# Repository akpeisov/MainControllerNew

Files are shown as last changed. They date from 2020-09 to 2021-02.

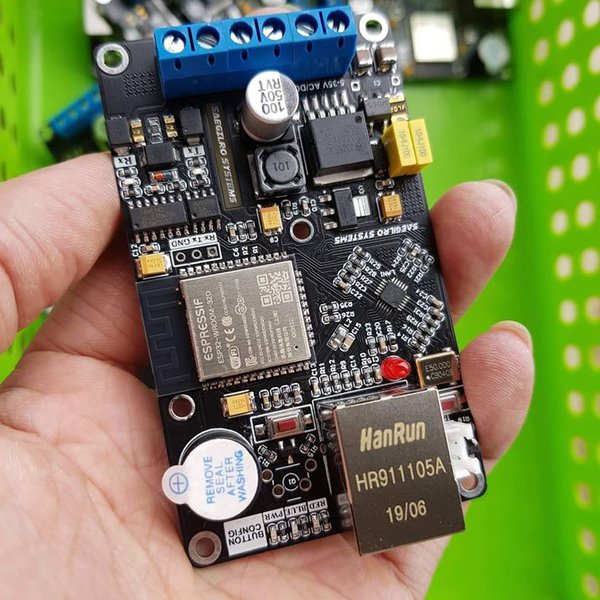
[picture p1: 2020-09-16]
esp32_example.jpg

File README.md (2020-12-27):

# MainControllerNew
Main controller on ESP32 (new version)

Переключение между кварцем и есп
(Top) - Component config - Ethernet - Support ESP32 internal EMAC controller - RMII clock mode

Flash

FT232	ESP32
TX	RX
RX	TX
DTR	GPIO0
RTS	EN

MQTT
Основное устройство (задается в параметрах)/slaveid/outputid

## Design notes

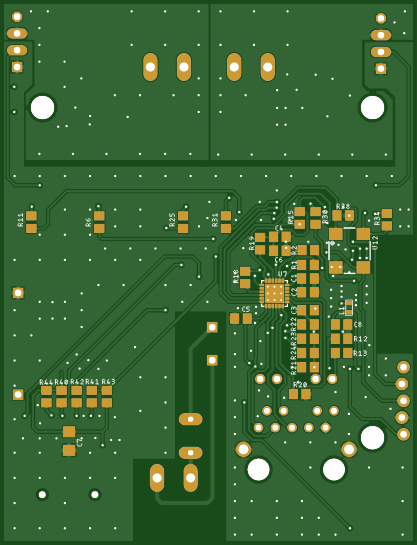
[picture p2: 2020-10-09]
board/back.png

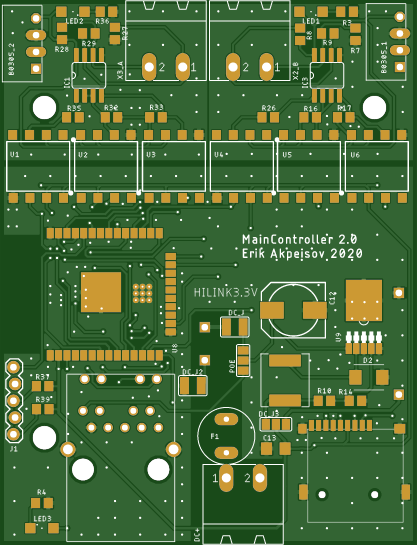
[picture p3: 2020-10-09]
board/face.png

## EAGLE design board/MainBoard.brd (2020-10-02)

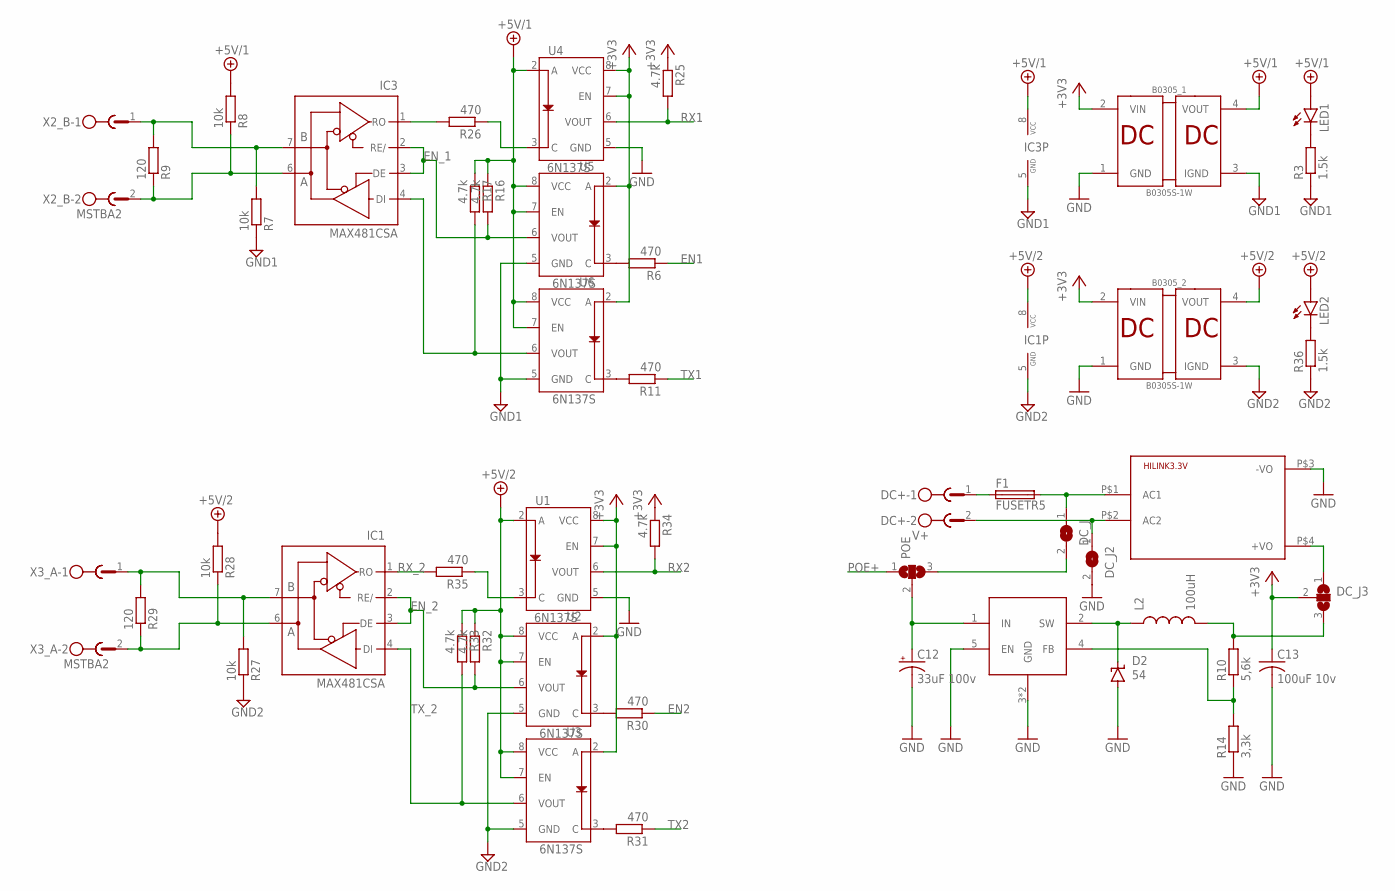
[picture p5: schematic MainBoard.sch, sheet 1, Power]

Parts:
B0305_1, B0305_2: B0305S-1W; B_S-1W
C12: 33uF 100v; 150CLZ-0810
C13: 100uF 10v; C1206
D2: 54; SMBJ
DC+: V+; MSTBA2
DC_J, DC_J2: SJW
DC_J3: SJ2W; SJ_2
F1: FUSETR5; TR5
HILINK3.3V: HLK-PM013W; HLK-PM01
IC1, IC3: MAX481CSA; SO08
L2: 100uH; CR75
LED1, LED2: LEDSML1206; SML1206
POE: SJ2W; SJ_2
R3, R36: 1.5k; R0805
R6, R11, R26, R30, R31, R35: 470; R0805
R7, R8, R27, R28: 10k; R0805
R9, R29: 120; R0805
R10: 5,6k; R0805
R14: 3,3k; R0805
R16, R17, R25, R32, R33, R34: 4.7k; R0805
U1, U2, U3, U4, U5, U6: 6N137S; 8-SMD
U9: XL7015; TO252-51
X2_B, X3_A: MSTBA2

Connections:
+3V3: B0305_1.2 (VIN), B0305_2.2 (VIN), C13.1, DC_J3.2, R25.1, R34.1, U1.7 (EN), U1.8 (VCC), U2.2 (A), U3.2 (A), U4.7 (EN), U4.8 (VCC), U5.2 (A), U6.2 (A); also elsewhere on the board
+5V/1: B0305_1.4 (VOUT), IC3.8 (VCC), LED1.A, R8.2, R16.1, R17.1, U4.2 (A), U5.7 (EN), U5.8 (VCC), U6.7 (EN), U6.8 (VCC)
+5V/2: B0305_2.4 (VOUT), IC1.8 (VCC), LED2.A, R28.2, R32.1, R33.1, U1.2 (A), U2.7 (EN), U2.8 (VCC), U3.7 (EN), U3.8 (VCC)
EN1: R6.1; also elsewhere on the board
EN2: R30.1; also elsewhere on the board
EN_1: IC3.2 (RE/), IC3.3 (DE), R16.2, U5.6 (VOUT)
EN_2: IC1.2 (RE/), IC1.3 (DE), R32.2, U2.6 (VOUT)
GND: B0305_1.1 (GND), B0305_2.1 (GND), C12.-, C13.2, D2.A, DC_J2.2, HILINK3.3V.P$3 (-VO), R14.1, U1.5 (GND), U4.5 (GND), U9.3 (GND), U9.5 (EN), U9.GND; also elsewhere on the board
GND1: B0305_1.3 (IGND), IC3.5 (GND), R3.1, R7.1, U5.5 (GND), U6.5 (GND)
GND2: B0305_2.3 (IGND), IC1.5 (GND), R27.1, R36.1, U2.5 (GND), U3.5 (GND)
unnamed: LED1.C, R3.2
unnamed: IC3.7 (B), R7.2, R9.2, X2_B.1
unnamed: IC3.6 (A), R8.1, R9.1, X2_B.2
unnamed: R10.1, R14.2, U9.4 (FB)
unnamed: DC_J.2, POE.3
unnamed: D2.C, L2.P$1 (1), U9.2 (SW)
unnamed: DC+.2, DC_J2.1, HILINK3.3V.P$2 (AC2)
unnamed: DC+.1, F1.1
unnamed: DC_J3.3, L2.P$2 (2), R10.2
unnamed: R6.2, U5.3 (C)
unnamed: R11.2, U6.3 (C)
unnamed: IC1.7 (B), R27.2, R29.2, X3_A.1
unnamed: R26.1, U4.3 (C)
unnamed: IC1.6 (A), R28.1, R29.1, X3_A.2
unnamed: R30.2, U2.3 (C)
unnamed: R31.2, U3.3 (C)
unnamed: R35.1, U1.3 (C)
unnamed: LED2.C, R36.2
unnamed: DC_J3.1, HILINK3.3V.P$4 (+VO)
unnamed: C12.+, POE.2, U9.1 (IN)
unnamed: DC_J.1, F1.2, HILINK3.3V.P$1 (AC1)
POE+: POE.1; also elsewhere on the board
RX1: R25.2, U4.6 (VOUT); also elsewhere on the board
RX2: R34.2, U1.6 (VOUT); also elsewhere on the board
RX485: IC3.1 (RO), R26.2
RX_2: IC1.1 (RO), R35.2
TX1: R11.1; also elsewhere on the board
TX2: R31.1; also elsewhere on the board
TX485: IC3.4 (DI), R17.2, U6.6 (VOUT)
TX_2: IC1.4 (DI), R33.2, U3.6 (VOUT)

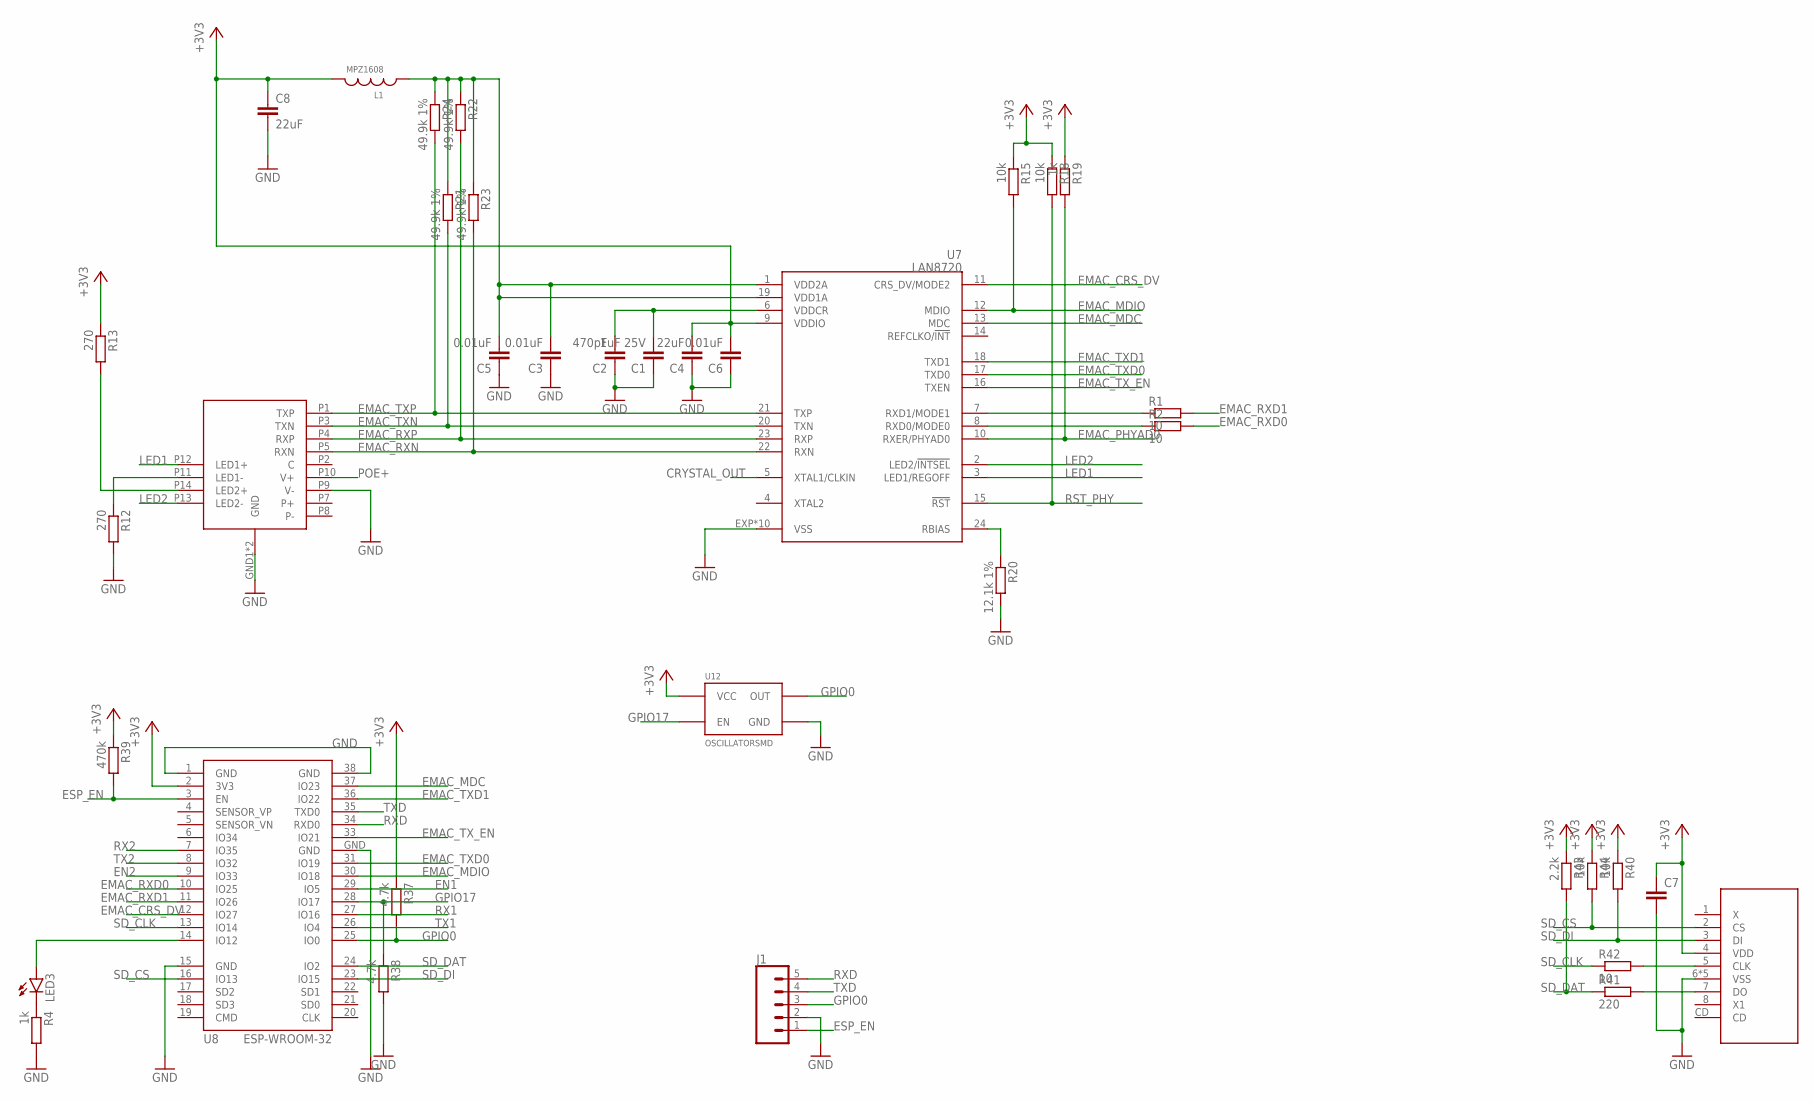
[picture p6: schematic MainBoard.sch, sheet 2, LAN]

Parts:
C1: 1uF 25V; C0805; MPN CC0603KPX7R8BB105
C2: 470pF; C0805; MPN CC0603JRX7R7BB471
C3, C5, C6: 0.01uF; C0805; MPN CC0603KRX7R6BB103
C4: 22uF; C0805; MPN CC0603KRX7R6BB103
C7: C-EUC1206; C1206
C8: 22uF; C0805; MPN CC0603MPX5R5BB226
J1: CONN_05LOCK; 1X05_LOCK
L1: MPZ1608; 1608
LED3: LEDSML1206; SML1206
R1, R2, R42: 10; R0805; MPN RC0603JR-0727RL
R4: 1k; R0805; MPN RC0603JR-07240RL
R12, R13: 270; R0805; MPN RC0603JR-07240RL
R15, R18, R40, R44: 10k; R0805; MPN RC0603JR-0727RL
R19: 1k; R0805; MPN RC0603JR-0727RL
R20: 12.1k 1%; R0805; MPN RC0603JR-0727RL
R21, R22, R23, R24: 49.9k 1%; R0805; MPN RC0603JR-0727RL
R37, R38: 4.7k; R0805; MPN RC0603JR-07240RL
R39: 470k; R0805; MPN RC0603JR-07240RL
R41: 220; R0805; MPN RC0603JR-0727RL
R43: 2.2k; R0805; MPN RC0603JR-0727RL
U7: LAN8720; QFN24; MPN LAN8720A-CP-ABC
U8: ESP-WROOM-32
U12: OSCILLATORSMD; CRYSTAL-SMD-7X5
U$1: MICROSD; MICROSDCARD
U$2: RJ45-1169

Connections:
+3V3: C4.2, C6.2, C7.1, C8.1, L1.P$2, R13.1, R15.1, R18.1, R19.1, R37.1, R39.1, R40.1, R43.1, R44.1, U7.9 (VDDIO), U8.2 (3V3), U12.P$4 (VCC), U$1.4 (VDD); also elsewhere on the board
CRYSTAL_OUT: U7.5 (XTAL1/CLKIN)
EMAC_CRS_DV: U7.11 (CRS_DV/MODE2), U8.12 (IO27)
EMAC_MDC: U7.13 (MDC), U8.37 (IO23)
EMAC_MDIO: R15.2, U7.12 (MDIO), U8.30 (IO18)
EMAC_PHYAD0: R19.2, U7.10 (RXER/PHYAD0)
EMAC_RBIAS: R20.1, U7.24 (RBIAS)
EMAC_RXD0: R2.2, U8.10 (IO25)
EMAC_RXD0_LAN: R2.1, U7.8 (RXD0/MODE0)
EMAC_RXD1: R1.2, U8.11 (IO26)
EMAC_RXD1_LAN: R1.1, U7.7 (RXD1/MODE1)
EMAC_RXN: R23.2, U7.22 (RXN), U$2.P5 (RXN)
EMAC_RXP: R22.2, U7.23 (RXP), U$2.P4 (RXP)
EMAC_TXD0: U7.17 (TXD0), U8.31 (IO19)
EMAC_TXD1: U7.18 (TXD1), U8.36 (IO22)
EMAC_TXN: R21.2, U7.20 (TXN), U$2.P3 (TXN)
EMAC_TXP: R24.2, U7.21 (TXP), U$2.P1 (TXP)
EMAC_TX_EN: U7.16 (TXEN), U8.33 (IO21)
EMAC_VDDCR: C1.2, C2.2, U7.6 (VDDCR)
EMAC_VDDXA: C3.2, C5.2, L1.P$1, R21.1, R22.1, R23.1, R24.1, U7.1 (VDD2A), U7.19 (VDD1A)
EN1: U8.29 (IO5); also elsewhere on the board
EN2: U8.9 (IO33); also elsewhere on the board
ESP_EN: J1.1, R39.2, U8.3 (EN)
GND: C1.1, C2.1, C3.1, C4.1, C5.1, C6.1, C7.2, C8.2, J1.2, R4.2, R12.2, R20.2, R38.2, U7.EXP (VSS), U7.GND1 (VSS), U7.GND2 (VSS), U7.GND3 (VSS), U7.GND4 (VSS), U7.GND5 (VSS), U7.GND6 (VSS), U7.GND7 (VSS), U7.GND8 (VSS), U7.GND9 (VSS), U8.1 (GND), U8.15 (GND), U8.38 (GND), U8.GND, U12.P$2 (GND), U$1.6 (VSS), U$1.GND (VSS), U$1.GND1 (VSS), U$1.GND2 (VSS), U$1.GND3 (VSS), U$2.GND1 (GND), U$2.GND2 (GND), U$2.P9 (V-); also elsewhere on the board
GPIO0: J1.3, R37.2, U8.25 (IO0), U12.P$3 (OUT)
GPIO17: R38.1, U8.28 (IO17), U12.P$1 (EN)
LED1: U7.3 (LED1/REGOFF), U$2.P12 (LED1+)
LED2: U7.2 (LED2/!INTSEL), U$2.P13 (LED2-)
unnamed: R13.2, U$2.P14 (LED2+)
unnamed: R12.1, U$2.P11 (LED1-)
unnamed: LED3.A, U8.14 (IO12)
unnamed: LED3.C, R4.1
unnamed: R41.2, U$1.7 (DO)
unnamed: R42.2, U$1.5 (CLK)
POE+: U$2.P10 (V+); also elsewhere on the board
RST_PHY: R18.2, U7.15 (!RST)
RX1: U8.27 (IO16); also elsewhere on the board
RX2: U8.7 (IO35); also elsewhere on the board
RXD: J1.5, U8.34 (RXD0)
SD_CLK: R42.1, U8.13 (IO14)
SD_CS: R44.2, U8.16 (IO13), U$1.2 (CS)
SD_DAT: R41.1, R43.2, U8.24 (IO2)
SD_DI: R40.2, U8.23 (IO15), U$1.3 (DI)
TX1: U8.26 (IO4); also elsewhere on the board
TX2: U8.8 (IO32); also elsewhere on the board
TXD: J1.4, U8.35 (TXD0)

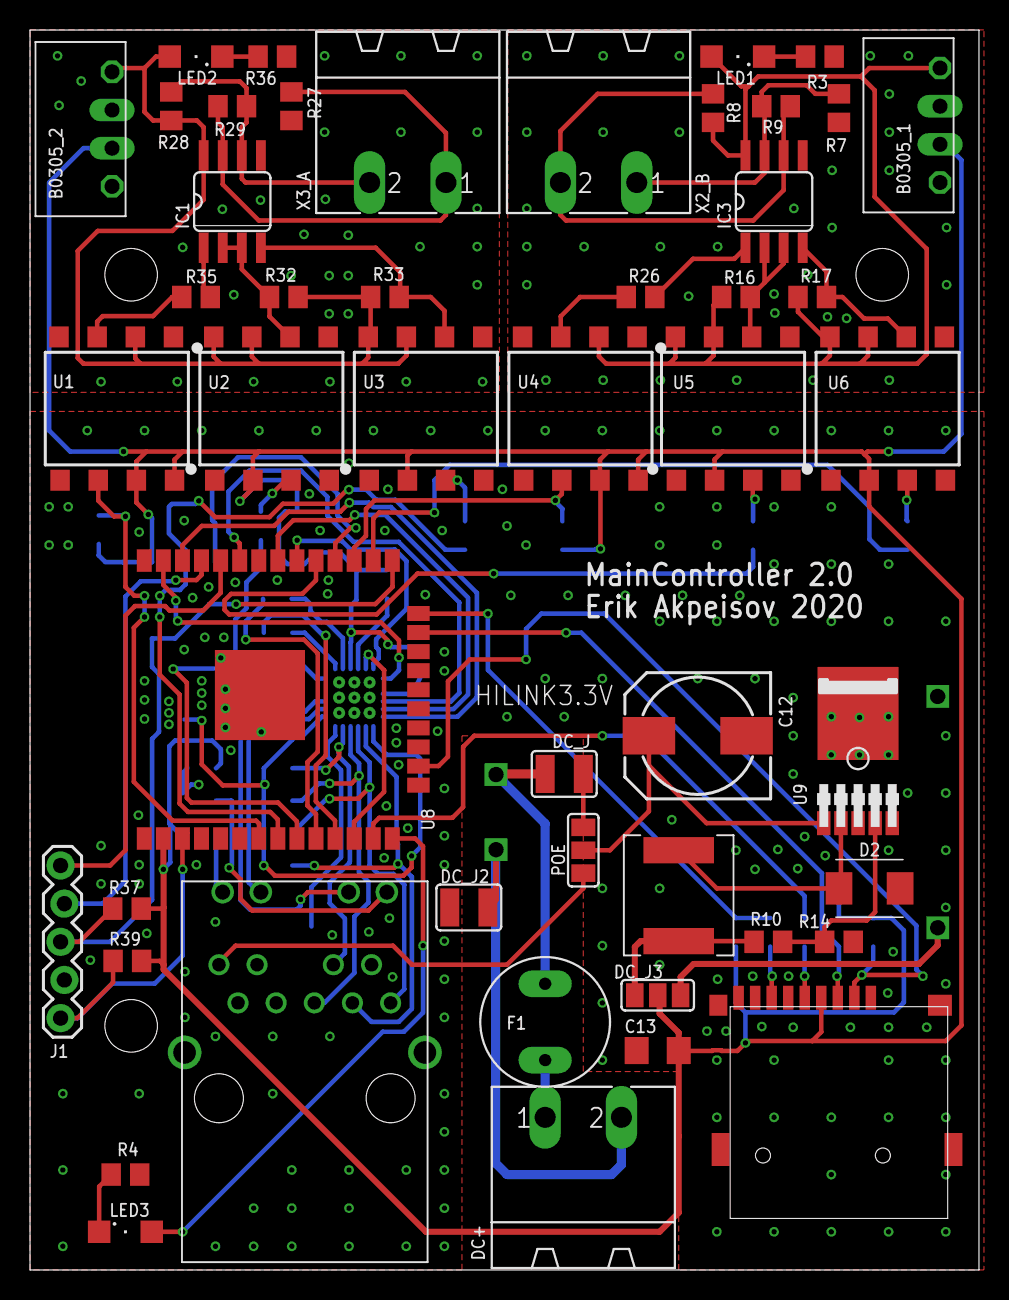
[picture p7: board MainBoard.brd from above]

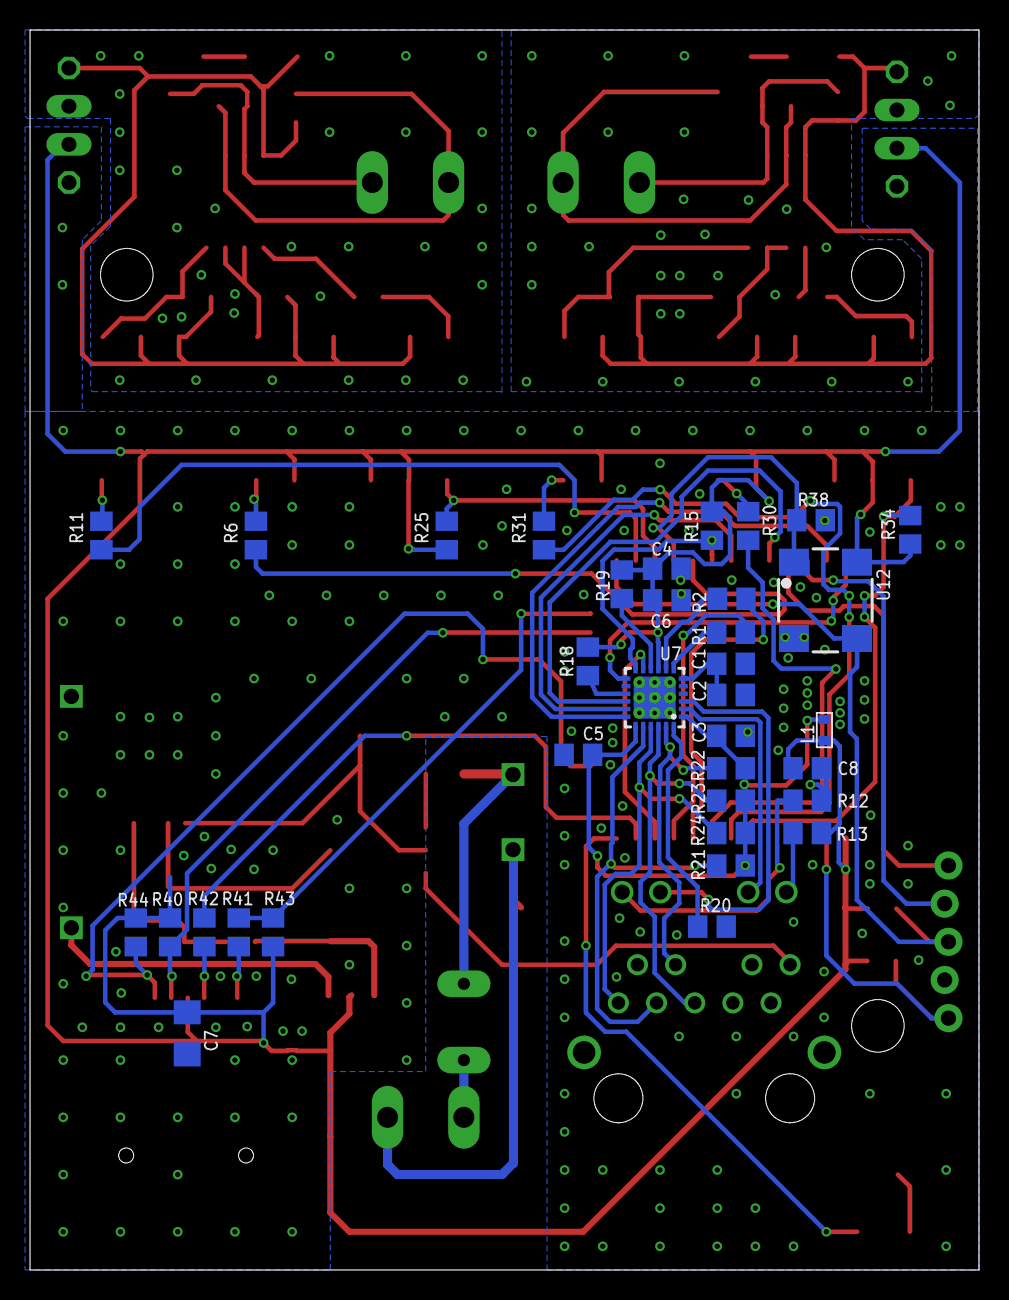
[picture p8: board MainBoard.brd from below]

Board: 2 copper layers, 63.2 x 82.5 mm, 85 parts (35 on the bottom side), 76 nets.

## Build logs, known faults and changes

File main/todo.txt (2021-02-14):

// todo.txt

+1. RGB лента via DMX
+2. SPIFFS + FTP
+ 3. Polling mode для овена
+ 4. OpenHab connect (MQTT/ModBus TCP)
5. RGB контроллер
+6. FTP
+7. WEB. При добавлении событий сразу должен быть слейв тот же, output the same as input

99. Под алису бы надо переделать логику. Все должно быть от устройства, его умения и т.д.

OWEN
вопросы
+1. чтение входов/выходов в виде чтения регистров
2. выставление выходов через указание регистра
3. привязка соответсвующего входа(ов) к выходу(ам)
4. включение/выключение определенного входа, указанного в виде бита или номера, в определенный регистр (т.к. запись в койл не поддерживается)
5. можно ли зашить событийную логику в овен

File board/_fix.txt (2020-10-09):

Забыл про 5 ногу 8720 - выход на кварц на GPIO0
Да еще бы выбор между кристалом и GPIO17

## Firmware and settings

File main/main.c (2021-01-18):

#include <stdio.h>
#include <string.h>
#include "freertos/FreeRTOS.h"
#include "freertos/task.h"
#include "esp_event.h"
#include "esp_log.h"
#include "sdkconfig.h"

#include "utils.h"
#include "storage.h"
#include "core.h"
#include "network.h"
#include "webServer.h"
#include "modbus.h"
#include "ftp.h"
#include "dmx.h"
#include "mqtt.h"

static const char *TAG = "MAIN";

void wdtMemoryTask(void *pvParameter) {
    ESP_LOGI(TAG, "Create watchdog memory task");
    uint8_t cnt=0;
    uint32_t minMem = getServiceConfigValueInt("wdtmemsize");
    while(1)
    {   
        // every 1 second     
        if (esp_get_free_heap_size() < minMem) {
            ESP_LOGE(TAG, "HEAP memory WDT triggered. Actual free memory is %d. Restarting...", esp_get_free_heap_size());
            //writeLog("E", "HEAP watchdog triggered. Restarting system...");
            esp_restart();
        }
        if (isReboot()) {
            static uint8_t cntReboot = 0;
            if (cntReboot++ >= 3)
                esp_restart();
        }
    
        if (cnt++ >= 60) {            
            char *uptime = getUpTime();            
            if (uptime != NULL) {
                ESP_LOGW(TAG, "Free heap size is %d. Min free is %d. Uptime %s", 
                         esp_get_free_heap_size(), esp_get_minimum_free_heap_size(), uptime);
                free(uptime);
            }
            cnt=0;
        }
        vTaskDelay(1000 / portTICK_RATE_MS);
    }
}

void modBusTask(void *pvParameter) {
    uint16_t pollingTime;
    ESP_LOGI(TAG, "Creating modBus task");
    SemaphoreHandle_t sem = getSemaphore();
    while(1) {     
        pollingTime = getServiceConfigValueInt("pollingTime");                         
        if (pollingTime == 0) {
            break;
        }
        if (xSemaphoreTake(sem, portMAX_DELAY) == pdTRUE) {
            //ESP_LOGI(TAG, "modBus task semaphore working");
            // Здесь происходит защищенный доступ к ресурсу.               
            pollingNew();
            // Отдаем "жетон".
            xSemaphoreGive(sem);
        } else {
            ESP_LOGI(TAG, "modBus task semaphore is busy");
        }        
        vTaskDelay(pollingTime / portTICK_RATE_MS);        
    }
    //vSemaphoreDelete(sem);
    vTaskDelete(NULL);
}

void app_main(void)
{
    ESP_LOGW(TAG, "Free heap size is %d", esp_get_free_heap_size());
    initLED();
    changeLEDStatus(LED_BOOTING);
    if (initStorage() != ESP_OK) {
        // alert!!!        
        changeLEDStatus(LED_ERROR);
        return;
    }
    
    loadConfig();
    ESP_LOGW(TAG, "Free heap size after load config %d", esp_get_free_heap_size());
    if (initNetwork() == ESP_OK) {
        initWebServer();
    }
    
    ESP_LOGW(TAG, "Free heap size after init network and web %d", esp_get_free_heap_size());
    
    mbInit();    
    ESP_LOGW(TAG, "Free heap size after init modbus %d", esp_get_free_heap_size());
    //sem_busy = xSemaphoreCreateMutex();
    createSemaphore();
    xTaskCreate(&wdtMemoryTask, "wdtMemoryTask", 4096, NULL, 5, NULL);
    xTaskCreate(&modBusTask, "modBusTask", 4096, NULL, 5, NULL);        

    changeLEDStatus(LED_NORMAL);
    writeLog("I", "System started");

    initMQTT();
    ESP_LOGW(TAG, "Free heap size after init MQTT %d", esp_get_free_heap_size());
    initFTP();
    ESP_LOGW(TAG, "Free heap size after init FTP %d", esp_get_free_heap_size());
    DMXInit();
    ESP_LOGW(TAG, "Free heap size after init DMX %d", esp_get_free_heap_size());

}

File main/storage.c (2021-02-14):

// storage file
// use internal storage, spiffs, sdcard
#include "nvs_flash.h"
#include "nvs.h"

#include "esp_vfs_semihost.h"
#include "esp_vfs_fat.h"

#include "sdcard.h"
#include "spiffs.h"
#include "webServer.h"
#include "utils.h"
#include "lwip/sockets.h"

#define USE_SD
#define PATH_SIZE 100
#define BUF_SIZE 2048
#define MOUNT_POINT "/storage"
#define MAX_FILE_SIZE   (200*1024) // 200 KB
#define MAX_FILE_SIZE_STR "200KB"

static const char *TAG = "STORAGE";

uint16_t bootId;
char *logPath;

esp_err_t initNVS() {
	esp_err_t err = nvs_flash_init();
    if (err == ESP_ERR_NVS_NO_FREE_PAGES || err == ESP_ERR_NVS_NEW_VERSION_FOUND) {
        // NVS partition was truncated and needs to be erased
        // Retry nvs_flash_init
        ESP_ERROR_CHECK(nvs_flash_erase());
        err = nvs_flash_init();
    }
    ESP_ERROR_CHECK( err );
    return err;
}

esp_err_t storeNumber(const char *key, const uint16_t value) {
    nvs_handle my_handle;
    esp_err_t err;

    // Open
    err = nvs_open("config", NVS_READWRITE, &my_handle);
    if (err != ESP_OK) return err;
    ESP_LOGD(TAG, "Open ok");

    err = nvs_set_u16(my_handle, key, value);

    if (err != ESP_OK) return err;
    ESP_LOGD(TAG, "Store ok");

    // Commit
    err = nvs_commit(my_handle);
    if (err != ESP_OK) return err;

    ESP_LOGD(TAG, "Commit ok");
    // Close
    nvs_close(my_handle);
    return ESP_OK;
}

esp_err_t restoreNumber(const char *key, uint16_t *value) {
    nvs_handle my_handle;
    esp_err_t err;

    // Open
    err = nvs_open("config", NVS_READWRITE, &my_handle);
    if (err != ESP_OK) return err;
    ESP_LOGD(TAG, "Open ok");

    err = nvs_get_u16(my_handle, key, value);

    if (err != ESP_OK) return err;
    ESP_LOGD(TAG, "Store ok");

    // Commit
    err = nvs_commit(my_handle);
    if (err != ESP_OK) return err;

    ESP_LOGD(TAG, "Commit ok");
    // Close
    nvs_close(my_handle);
    return ESP_OK;
}

uint16_t getLastId() {
    uint16_t id = 0;
    restoreNumber("lastid", &id);
    id++;
    storeNumber("lastid", id);
    return id;    
}

esp_err_t initStorage() {
	initNVS();
	#ifdef USE_SD
	if (initSD(MOUNT_POINT) != ESP_OK) {
		ESP_LOGE(TAG, "Can't init SD. Trying init SPIFFS");
		if (initSPIFFS(MOUNT_POINT) != ESP_OK) {
			ESP_LOGE(TAG, "Can't init SPIFFS");
            return ESP_FAIL;
		} else {
            ESP_LOGI(TAG, "Using SPIFFS");
        }
	}	
	#else
	if (initSPIFFS(MOUNT_POINT) != ESP_OK) {
		ESP_LOGE(TAG, "Can't init SPIFFS");
        return ESP_FAIL;
	}		
	#endif
        
    char *buf = malloc(5);
    itoa(getLastId(), buf, 10);

    logPath = malloc(16+strlen(MOUNT_POINT));
    strcpy(logPath, MOUNT_POINT);    
    strcat(logPath, "/logs/");
    strcat(logPath, buf);
    strcat(logPath, ".txt");    
    free(buf);
    return ESP_OK;
}

esp_err_t loadTextFile(char * filename, char ** buffer) {    
	// аллокейтит буфер и считает весь файл в него
    char path[PATH_SIZE];
    strcpy(path, MOUNT_POINT);    
    strcat(path, filename);    
    ESP_LOGI(TAG, "Opening file path %s", path);
    FILE* f = fopen(path, "r");    
    if (f == NULL) {
        ESP_LOGE(TAG, "Failed to open file %s for reading", path);
        return ESP_FAIL;
    }

    fseek(f, 0L, SEEK_END);
    uint16_t bufSize = ftell(f);
    fseek(f, 0L, SEEK_SET);
    
    *buffer = (char*)malloc(bufSize+1);
    if (*buffer == NULL) {
        ESP_LOGE(TAG, "Can't allocate buffer for file %s", filename);
        return ESP_FAIL;
    } else {
        ESP_LOGD(TAG, "Allocate ok");
    }

    if (fread(*buffer, 1, bufSize, f) < 1) {
        ESP_LOGE(TAG, "Can't fread");
    }
    buffer[0][bufSize] = 0;    
    fclose(f);
    ESP_LOGD(TAG, "getTextFile finish");
    return ESP_OK;
}

esp_err_t saveTextFile(char * filename, char * buffer) {
    // save file to filesystem
    uint16_t bufSize = strlen(buffer);
    char path[PATH_SIZE];
    strcpy(path, MOUNT_POINT);    
    strcat(path, filename);    
    ESP_LOGI(TAG, "Saving file path %s", path);
    
    FILE *fd = fopen(path, "w");
    if (!fd) {
        ESP_LOGE(TAG, "Failed to create file %s", path);        
        return ESP_FAIL;
    }
   
    if (bufSize != fwrite(buffer, 1, bufSize, fd)) {
        /* Couldn't write everything to file!
         * Storage may be full? */
        fclose(fd);
        unlink(path);
        ESP_LOGE(TAG, "File write failed!");
        return ESP_FAIL;
    }
        
    /* Close file upon upload completion */
    fclose(fd);
    ESP_LOGI(TAG, "File saved successfully");

    return ESP_OK;
}

esp_err_t getFileWebPath(httpd_req_t *req, char* path) {    
    ESP_LOGI(TAG, "Opening file path %s", path);
    
    FILE* f = fopen(path, "r");    
    if (f == NULL) {
        ESP_LOGE(TAG, "Failed to open file %s for reading", req->uri);
        return ESP_FAIL;
    }

    char *buffer = malloc(BUF_SIZE);    
    if (buffer == NULL) {
        ESP_LOGE(TAG, "Failed to allocate buffer");
        return ESP_FAIL;
    }

    set_content_type_from_file(req, path);
    size_t chunksize;
    do {
        /* Read file in chunks into the scratch buffer */
        //chunksize = fread(buffer, 1, SCRATCH_BUFSIZE, f);
        chunksize = fread(buffer, 1, BUF_SIZE, f);

        if (chunksize > 0) {
            /* Send the buffer contents as HTTP response chunk */
            if (httpd_resp_send_chunk(req, buffer, chunksize) != ESP_OK) {
                fclose(f);
                ESP_LOGE(TAG, "File sending failed!");
                /* Abort sending file */
                httpd_resp_sendstr_chunk(req, NULL);
                /* Respond with 500 Internal Server Error */
                httpd_resp_send_err(req, HTTPD_500_INTERNAL_SERVER_ERROR, "Failed to send file");
                free(buffer);
                return ESP_FAIL;
            }
        }

        /* Keep looping till the whole file is sent */
    } while (chunksize != 0);
    
    fclose(f);
    httpd_resp_send_chunk(req, NULL, 0);
    free(buffer);
    return ESP_OK;
}

esp_err_t getFileWeb(httpd_req_t *req) {    
    char path[PATH_SIZE];
    strcpy(path, getWWWroot());    
    if (req->uri[strlen(req->uri) - 1] == '/') 
        strcat(path, "/index.html");
    else   
        strcat(path, req->uri);    
    return getFileWebPath(req, path);
}    

esp_err_t getLogFile(httpd_req_t *req) {    
    return getFileWebPath(req, logPath);
}

// esp_err_t getFileWeb(httpd_req_t *req) {
//     char path[PATH_SIZE];
//     strcpy(path, getWWWroot());    
//     if (req->uri[strlen(req->uri) - 1] == '/') 
//         strcat(path, "/index.html");
//     else   
//     	strcat(path, req->uri);    
//     ESP_LOGI(TAG, "Opening file path %s", path);
    
//     FILE* f = fopen(path, "r");    
//     if (f == NULL) {
//         ESP_LOGE(TAG, "Failed to open file %s for reading", req->uri);
//         return ESP_FAIL;
//     }
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

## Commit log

2020-09-16 OTA added
    [partitions.csv]
2020-09-24 added switchOutput method
2020-10-02 added boards
    [MainBoard.brd, MainBoard.sch]

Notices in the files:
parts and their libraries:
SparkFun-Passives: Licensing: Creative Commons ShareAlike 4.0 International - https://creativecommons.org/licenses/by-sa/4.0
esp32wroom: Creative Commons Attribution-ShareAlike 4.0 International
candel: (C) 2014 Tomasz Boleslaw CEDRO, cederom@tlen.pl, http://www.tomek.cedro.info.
